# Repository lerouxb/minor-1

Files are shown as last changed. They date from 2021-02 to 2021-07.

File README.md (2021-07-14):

# minor-1

Credit card sized capacitive touch toy piano.

Just the absolute minimum:

* QT60140 16 key touch sensor
* ATtiny1614 microcontroller
* Piezo transducer
* MCP6001R op-amp as buffer for the piezo
* CR2032 coin cell battery
* SPDT power switch
* 13 keys, octave +/- and change sound touch buttons
* Currently unpopulated footprint for NOR flash
* P-channel MOSFET for completely cutting power

This uses the attiny's 8-bit DAC at 25khz to play notes. The microcontroller can shut down power to the op-amp/piezo and the flash chip when not in use. It also sleeps until a touch button is pressed or until there's activity on the serial port.

There's a simple browser page to log the button presses, read status and read/write the setups. Useful for configurating the touch controller. Could be useful in future for programming the NOR flash or configuring the sounds.

Still very much a work in progress, but it can already play tunes.

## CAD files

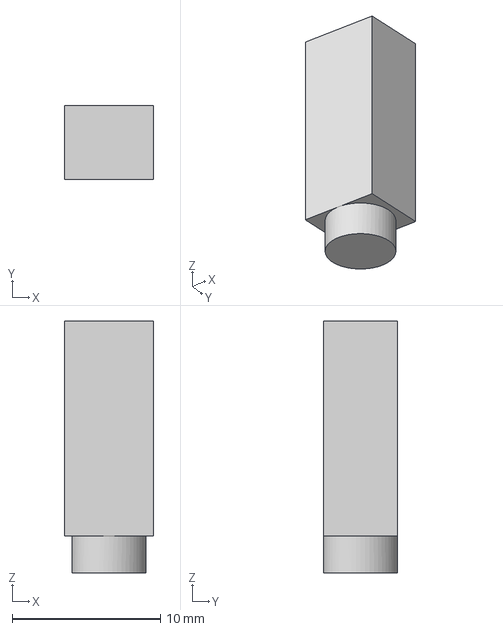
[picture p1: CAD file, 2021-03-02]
pcb/minor-1/footprints/SJ-3523-SMT-TR.step
6.00 x 5.00 x 17.0 mm

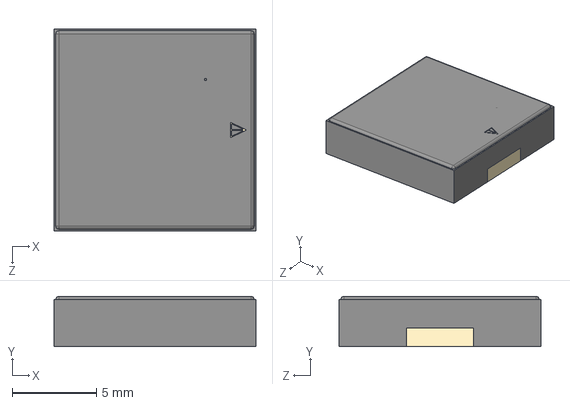
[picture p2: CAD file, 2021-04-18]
pcb/minor-cap/PKLCS1212E2000-R1--3DModel-STEP-56544.STEP
12.0 x 3.00 x 12.0 mm

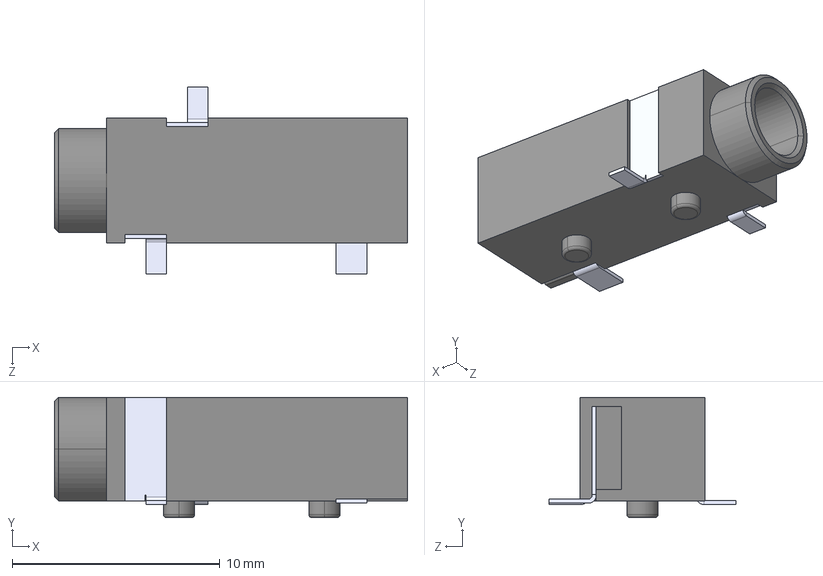
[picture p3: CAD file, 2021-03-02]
pcb/minor-1/footprints/SJ-3523-SMT-TR--3DModel-STEP-56544.STEP
17.0 x 5.80 x 9.00 mm

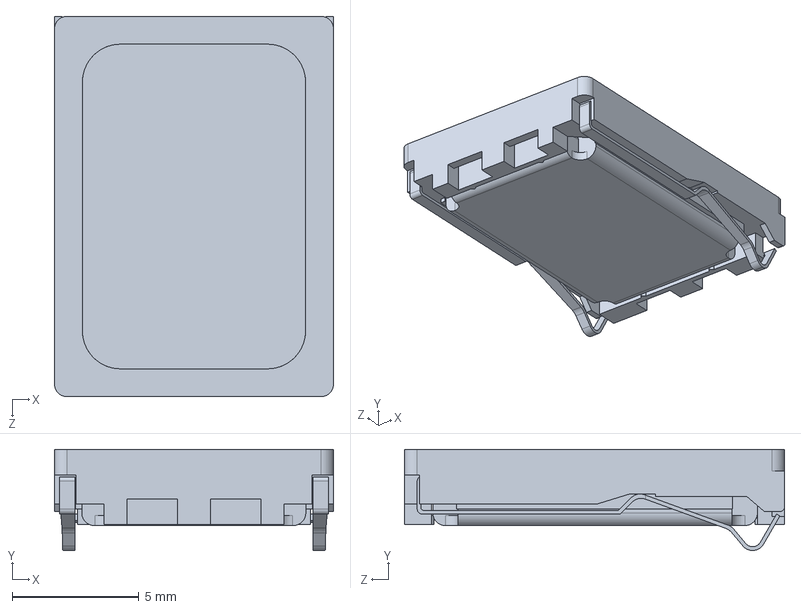
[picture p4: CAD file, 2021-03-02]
pcb/minor-1/footprints/CUI_DEVICES_CMS-15113-078S.step
11.0 x 3.98 x 15.0 mm

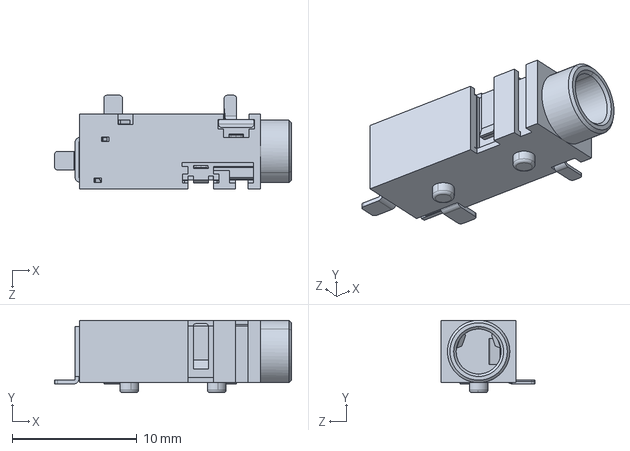
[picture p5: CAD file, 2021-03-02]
pcb/minor-1/footprints/CUI_DEVICES_SJ2-3592B-SMT-TR.step
19.0 x 5.80 x 7.50 mm

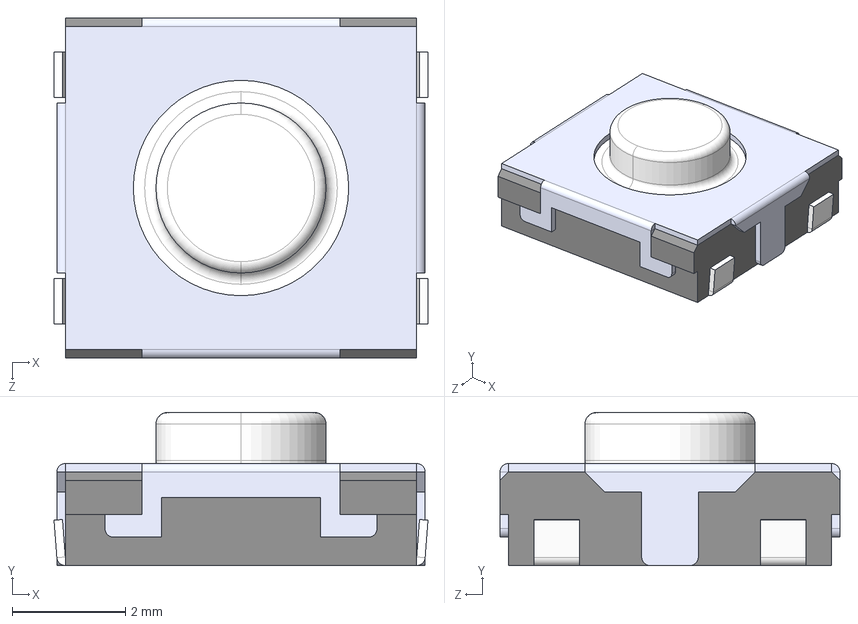
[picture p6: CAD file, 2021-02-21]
pcb/minor-1/footprints/EVQ-Q2B02W--3DModel-STEP-1.STEP
6.60 x 2.70 x 6.00 mm

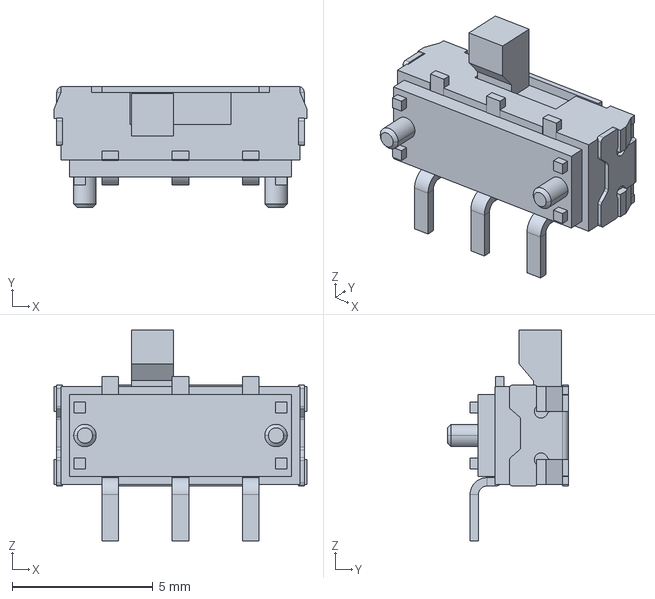
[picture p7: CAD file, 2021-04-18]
pcb/minor-cap/JS102011SAQN--3DModel-Eagle-1.STEP
9.00 x 4.30 x 7.50 mm

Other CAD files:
pcb/minor-1/footprints/SJ-3523-SMT-TR.f3d

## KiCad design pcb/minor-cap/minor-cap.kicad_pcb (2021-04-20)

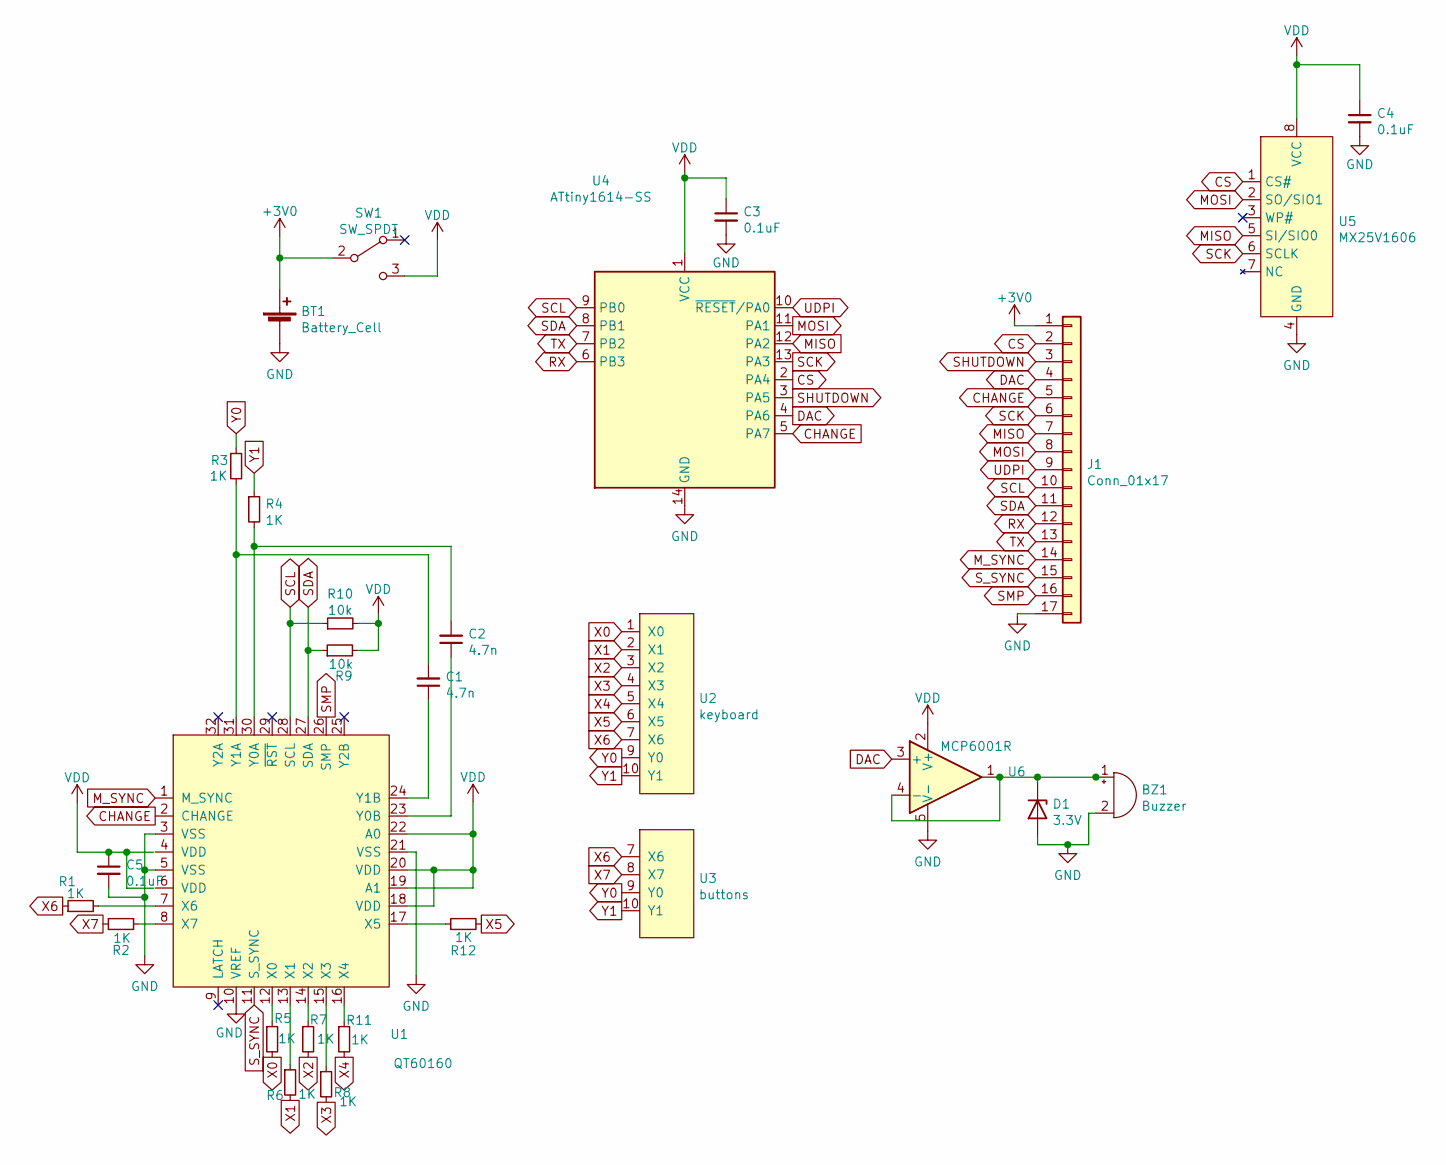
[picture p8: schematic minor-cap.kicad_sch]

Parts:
BT1: Battery_Cell; BatteryHolder_Keystone_3034_1x20mm
BZ1: Buzzer; Buzzer_Murata_PKLCS1212E
C1, C2: 4.7n; C_0603_1608Metric
C3, C4, C5: 0.1uF; C_0603_1608Metric
D1: 3.3V; D_SOD-323
J1: Conn_01x17; 01x17_custom
R1, R2, R3, R4, R5, R6, R7, R8, R11, R12: 1K; R_0603_1608Metric
R9, R10: 10k; R_0603_1608Metric
SW1: SW_SPDT; SW_SPDT_CK-JS102011SAQN
U1: QT60160; QFN-32-1EP_5x5mm_P0.5mm_EP3.1x3.1mm
U2: keyboard; 13-keys
U3: buttons; 3-buttons
U4: ATtiny1614-SS; SOIC-14_3.9x8.7mm_P1.27mm
U5: MX25V1606; SOP-8_3.9x4.9mm_P1.27mm
U6: MCP6001R; SOT-23-5

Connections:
+3V0: BT1.1 (+), J1.1, SW1.2 (B)
CHANGE: J1.5, U1.2 (CHANGE), U4.5 (PA7)
CS: J1.2, U4.2 (PA4), U5.1 (CS#)
DAC: J1.4, U4.4 (PA6), U6.3 (+)
GND: BT1.2 (-), BZ1.2 (+), C3.2, C4.2, C5.2, D1.2 (A), J1.17, U1.3 (VSS), U1.5 (VSS), U1.10 (VREF), U1.21 (VSS), U4.14 (GND), U5.4 (GND), U6.5 (V-)
MISO: J1.7, U4.12 (PA2), U5.5 (SI/SIO0)
MOSI: J1.8, U4.11 (PA1), U5.2 (SO/SIO1)
M_SYNC: J1.14, U1.1 (M_SYNC)
unnamed: BZ1.1 (-), D1.1 (K), U6.1, U6.4 (-)
unnamed: C1.1, U1.24 (Y1B)
unnamed: C1.2, R3.2, U1.31 (Y1A)
unnamed: C2.1, U1.23 (Y0B)
unnamed: C2.2, R4.2, U1.30 (Y0A)
unnamed: R1.2, U1.7 (X6)
unnamed: R2.1, U1.8 (X7)
unnamed: R5.1, U1.12 (X0)
unnamed: R6.1, U1.13 (X1)
unnamed: R7.1, U1.14 (X2)
unnamed: R8.1, U1.15 (X3)
unnamed: R11.1, U1.16 (X4)
unnamed: R12.1, U1.17 (X5)
RX: J1.12, U4.6 (PB3)
SCK: J1.6, U4.13 (PA3), U5.6 (SCLK)
SCL: J1.10, R10.1, U1.28 (SCL), U4.9 (PB0)
SDA: J1.11, R9.1, U1.27 (SDA), U4.8 (PB1)
SHUTDOWN: J1.3, U4.3 (PA5)
SMP: J1.16, U1.26 (SMP)
S_SYNC: J1.15, U1.11 (S_SYNC)
TX: J1.13, U4.7 (PB2)
UDPI: J1.9, U4.10 (~RESET~/PA0)
VDD: C3.1, C4.1, C5.1, R9.2, R10.2, SW1.3 (C), U1.18 (VDD), U1.19 (A1), U1.20 (VDD), U1.22 (A0), U4.1 (VCC), U5.8 (VCC), U6.2 (V+)
X0: R5.2, U2.1 (X0)
X1: R6.2, U2.2 (X1)
X2: R7.2, U2.3 (X2)
X3: R8.2, U2.4 (X3)
X4: R11.2, U2.5 (X4)
X5: R12.2, U2.6 (X5)
X6: R1.1, U2.7 (X6), U3.7 (X6)
X7: R2.2, U3.8 (X7)
Y0: R3.1, U2.9 (Y0), U3.9 (Y0)
Y1: R4.1, U2.10 (Y1), U3.10 (Y1)

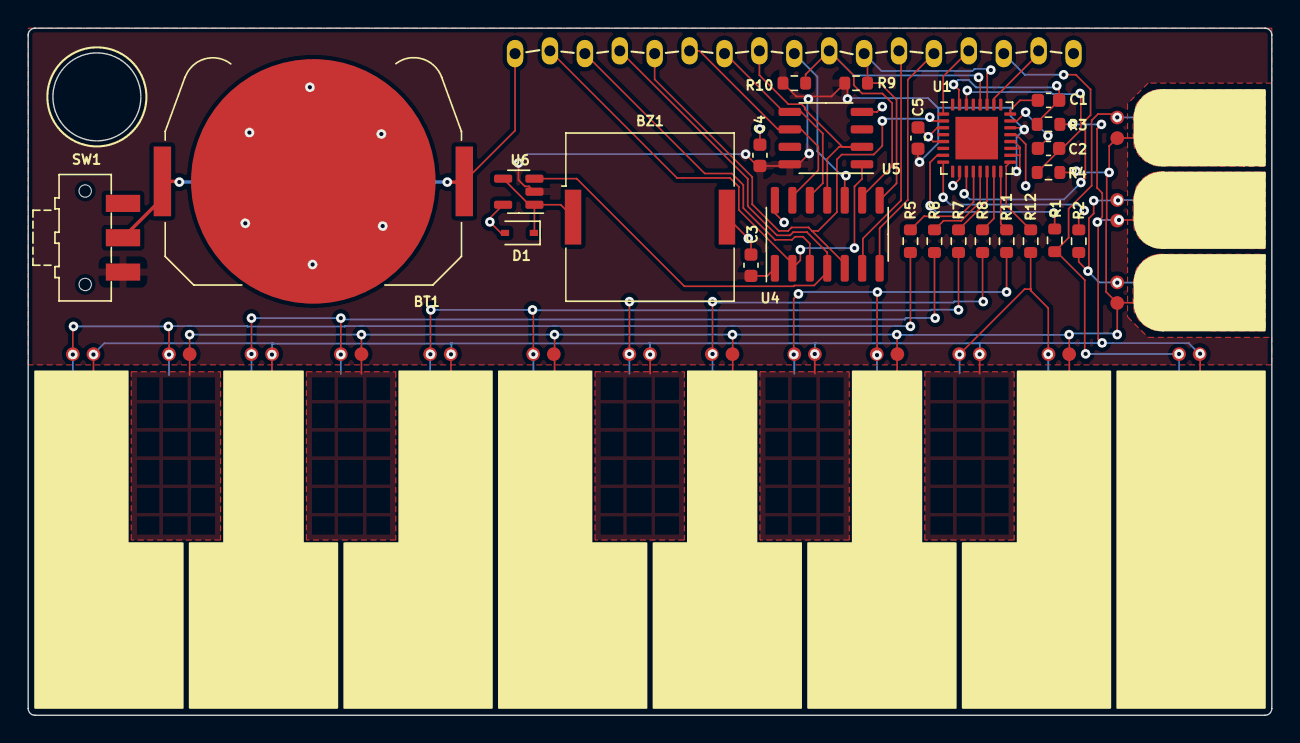
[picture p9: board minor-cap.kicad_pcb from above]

Board: 2 copper layers, 90.5 x 50.0 mm, 28 parts (0 on the bottom side), 41 nets.

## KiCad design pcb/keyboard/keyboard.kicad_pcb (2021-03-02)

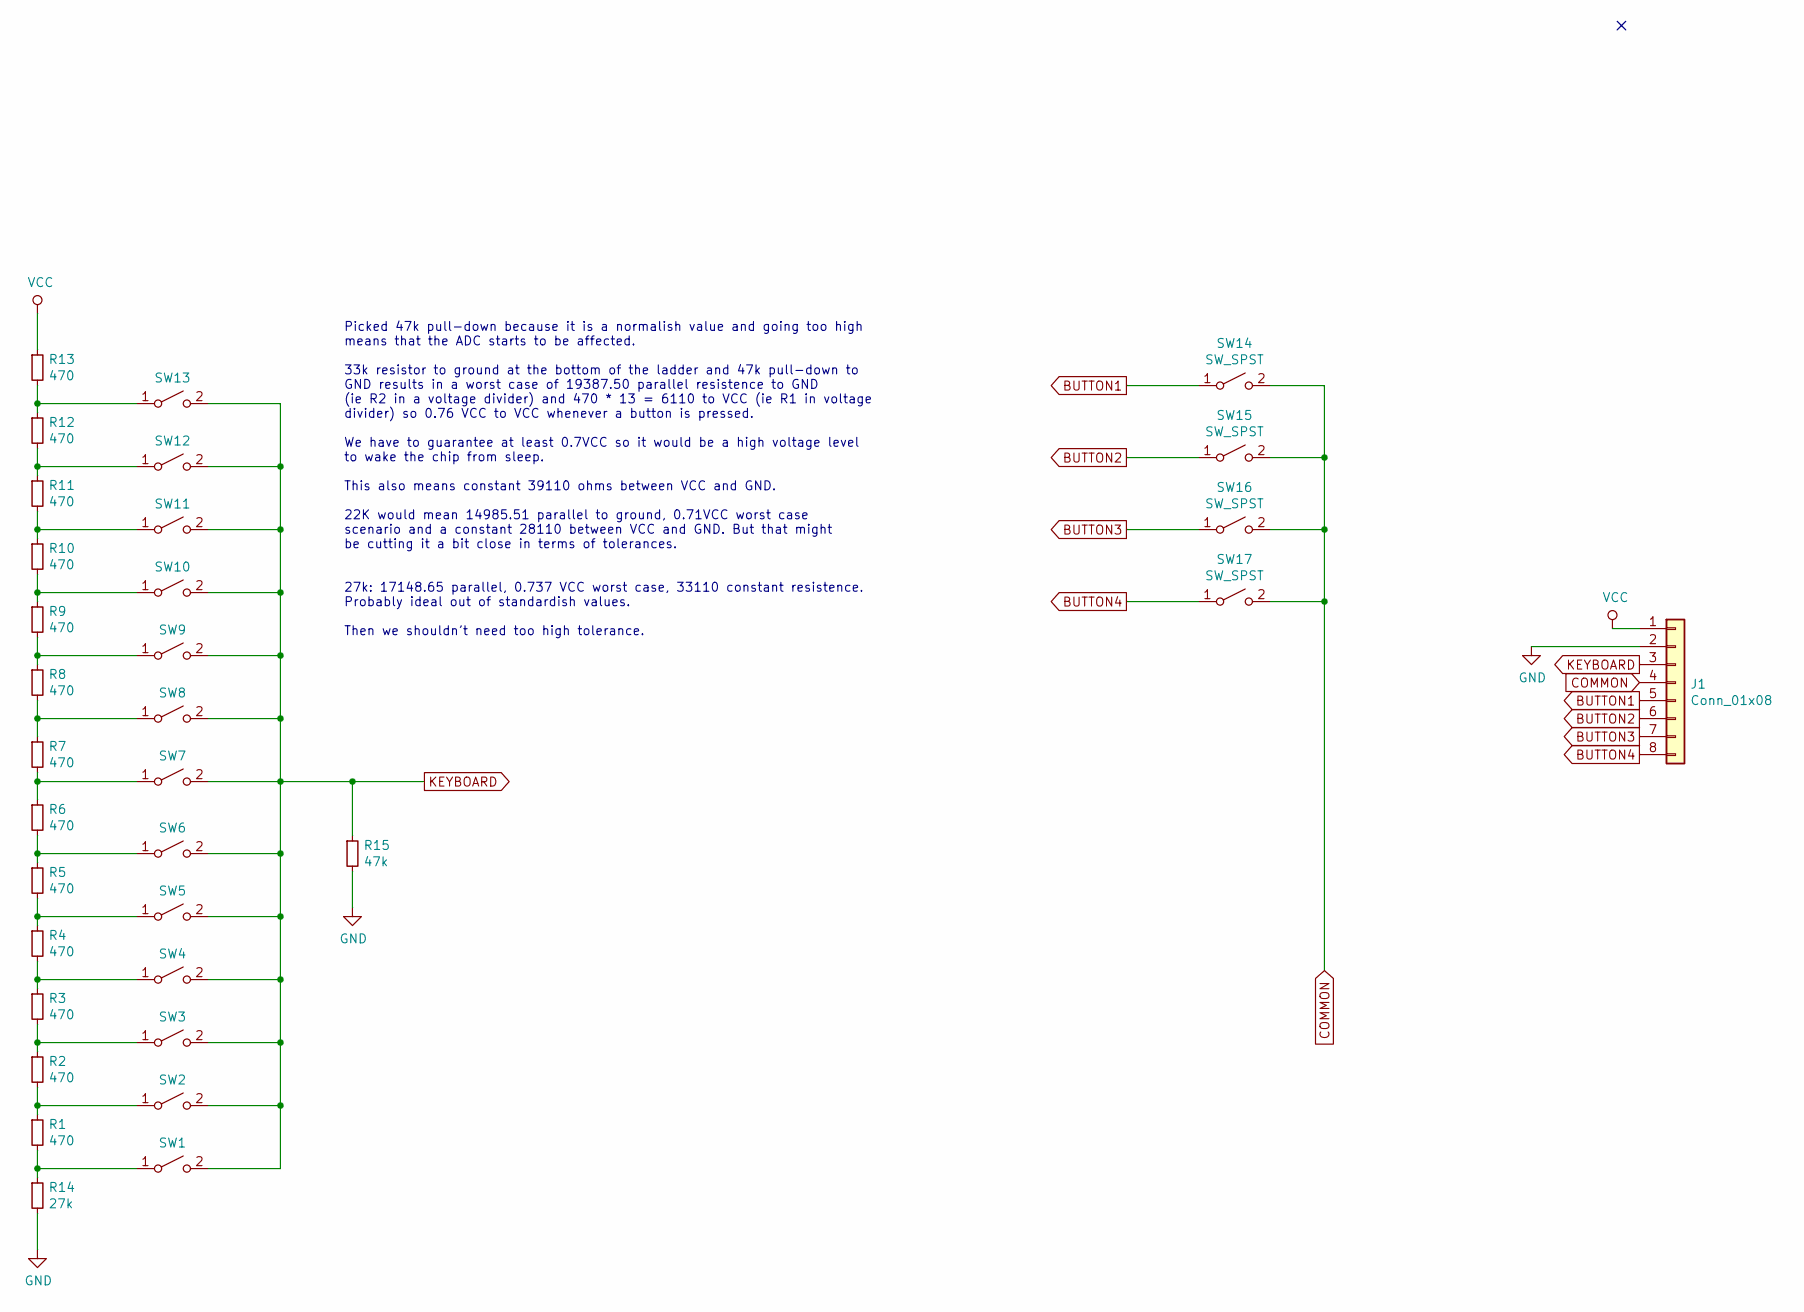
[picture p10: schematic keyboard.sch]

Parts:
J1: Conn_01x08; Pin_Header_Straight_1x08_Pitch2.54mm
R1, R2, R3, R4, R5, R6, R7, R8, R9, R10, R11, R12, R13: 470; R_0603
R14: 27k; R_0603
R15: 47k; R_0603
SW1, SW2, SW3, SW4, SW5, SW6, SW7, SW8, SW9, SW10, SW11, SW12, SW13, SW14, SW15, SW16, SW17: SW_SPST; EVQ-Q2B03W

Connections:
BUTTON1: J1.5, SW14.1 (A)
BUTTON2: J1.6, SW15.1 (A)
BUTTON3: J1.7, SW16.1 (A)
BUTTON4: J1.8, SW17.1 (A)
COMMON: J1.4, SW14.2 (B), SW15.2 (B), SW16.2 (B), SW17.2 (B)
GND: J1.2, R14.2, R15.2
KEYBOARD: J1.3, R15.1, SW1.2 (B), SW2.2 (B), SW3.2 (B), SW4.2 (B), SW5.2 (B), SW6.2 (B), SW7.2 (B), SW8.2 (B), SW9.2 (B), SW10.2 (B), SW11.2 (B), SW12.2 (B), SW13.2 (B)
unnamed: R1.1, R2.2, SW2.1 (A)
unnamed: R1.2, R14.1, SW1.1 (A)
unnamed: R2.1, R3.2, SW3.1 (A)
unnamed: R3.1, R4.2, SW4.1 (A)
unnamed: R4.1, R5.2, SW5.1 (A)
unnamed: R5.1, R6.2, SW6.1 (A)
unnamed: R6.1, R7.2, SW7.1 (A)
unnamed: R7.1, R8.2, SW8.1 (A)
unnamed: R8.1, R9.2, SW9.1 (A)
unnamed: R10.1, R11.2, SW11.1 (A)
unnamed: R9.1, R10.2, SW10.1 (A)
unnamed: R11.1, R12.2, SW12.1 (A)
unnamed: R12.1, R13.2, SW13.1 (A)
VCC: J1.1, R13.1

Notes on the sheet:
Picked 47k pull-down because it is a normalish value and going too high means that the ADC starts to be affected. 33k resistor to ground at the bottom of the ladder and 47k pull-down to GND results in a worst case of 19387.50 parallel resistence to GND (ie R2 in a voltage divider) and 470 * 13 = 61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

Board: 2 copper layers, 33 parts (0 on the bottom side), 21 nets, no tracks yet.

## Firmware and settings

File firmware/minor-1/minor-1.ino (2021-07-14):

#include <avr/sleep.h>
#include "pins.h"
#include "engine.h"
#include "interface.h"

// TODO: check every menu option

#ifndef MILLIS_USE_TIMERD0
#error "This sketch is written for use with TCD0 as the millis timing source"
#endif

// engine.cpp
extern boolean isPlaying; // TODO: make it a function?

// globals used by interface and engine
volatile uint32_t tick = 0;
volatile uint8_t sample = 127;

// globals used by interface
volatile bool touchChanged = false;
volatile bool goToSleep = false;


void setup() {

    DACReference(INTERNAL2V5);

    // setup a timer overflow interrupt to fire at 25khz
    // system clock is 20Mhz. Prescaler is 16. Period is 49 (so it will be 49+1 = 50)
    TCA0.SINGLE.INTCTRL = 0 << TCA_SINGLE_CMP0_bp   /* Compare 0 Interrupt: disabled */
                          | 0 << TCA_SINGLE_CMP1_bp /* Compare 1 Interrupt: disabled */
                          | 0 << TCA_SINGLE_CMP2_bp /* Compare 2 Interrupt: disabled */
                          | 1 << TCA_SINGLE_OVF_bp; /* Overflow Interrupt: enabled */

    TCA0.SINGLE.PER = 49; /* 49 + 1 == 50 */

    TCA0.SINGLE.CTRLA = TCA_SINGLE_CLKSEL_DIV16_gc /* System Clock / 16 */
                        | 1 << TCA_SINGLE_ENABLE_bp /* Module Enable: enabled */;

    //pinMode(LED_PIN, OUTPUT);
    pinMode(DAC_PIN, OUTPUT);
    pinMode(SHUTDOWN_PIN, OUTPUT);
    pinMode(CHANGE_PIN, INPUT_PULLUP);

    // PIN_PA7
    PORTA.PIN7CTRL |= 0x01; // interrupt on change

    // TODO: make sure all pins are dealt with from a power consumption perspective

    Serial.begin(57600); // at 115200 it wakes too slowly from sleep to be able to read serial communications
    Wire.begin();

    setupInterface();

    Serial.println("OK");

    recalibrateTouch();

    Serial.println("recalibrated");

    // TODO: uart doesn't stay active during power down. it can stay active during standby if we enable that (somewhere?), but maybe we can just set a pin interrupt on RX?
    set_sleep_mode(SLEEP_MODE_STANDBY);
    USART0.CTRLB |= USART_SFDEN_bm; // enable start of frame detection mode
    sleep_enable();
}


void loop() {

    updateInterface();

    // clear interrupts before double-checking to eliminate race conditions
    // see https://www.nongnu.org/avr-libc/user-manual/group__avr__sleep.html
    cli();
    if (goToSleep) {
        // reset goToSleep regardless so that it will be re-set if we don't go to sleep and it still applies
        goToSleep = false;

        // don't go to sleep if there are unprocessed touch events because the touch sensor won't set the change pin high again until we read it. Therefore we have to make very sure we read everything and that it is low so that things don't get stuck
        if (!touchChanged && !isPlaying && digitalRead(CHANGE_PIN) == LOW) {
            sei();
            Serial.flush();
            Serial.println("going to sleep");
            Serial.flush();

            // tripple-check because interrupts are on and we printed things which takes time
            cli();
            if (digitalRead(CHANGE_PIN) == LOW) {
                sei(); // in theory sleep_cpu() straight after sei() is atomic
                sleep_cpu();
            }

            Serial.println("awake!");
        }
    }

    sei(); // in case either if up top was false
}

ISR(TCA0_OVF_vect) {

    //digitalWriteFast(LED_PIN, true);

    ++tick;

    if (isPlaying) {
        digitalWriteFast(SHUTDOWN_PIN, false); // on before next sample
    }
    else {
        goToSleep = true; // this is so the main loop can put the chip to sleep after this interrupt ran
        digitalWriteFast(SHUTDOWN_PIN, true); // off before next sample
    }

    // write the previously calculated sample first so the timing is reliable no matter how long it takes to calculate the next sample
    analogWrite(DAC_PIN, sample);

    // calculate the sample for next time
    sample = nextSample();

    //digitalWriteFast(LED_PIN, false); // TODO: optimise

    // The interrupt flag has to be cleared manually
    TCA0.SINGLE.INTFLAGS = TCA_SINGLE_OVF_bm;
}

ISR(PORTA_PORT_vect) {
    byte flags = PORTA.INTFLAGS;
    PORTA.INTFLAGS = flags; //clear flags

    if (digitalRead(CHANGE_PIN) == HIGH) {
        touchChanged = true;
    }
}

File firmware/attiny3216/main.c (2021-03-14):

#include <string.h>
#include <atmel_start.h>
#include <util/delay.h>
#include "notes.h"
#include "waveforms.h"

// about 25000 ticks per second
#define DEBOUNCE_TICKS 1250
#define REPEAT_TICKS1 6000 // first repeat is slower to prevent accidents
#define REPEAT_TICKS2 2000

volatile adc_result_t ADC_0_measurement;
extern volatile uint32_t tick;

// sound stuff
int32_t jump = 44946936; // Middle C
uint8_t octave = 0;
waveform_t waveform = Pulse;

// button stuff
uint32_t last_tick = 0;
uint16_t bounce = 0;
uint16_t repeat = 0;
bool repeating = false;

void my_function ();


int8_t check_up_down() {

    int8_t delta = 0;

    // tick wraps about once every 2 days :)
    if (last_tick > tick) {
        last_tick = 0;
    }

    while (last_tick < tick) {
        ++last_tick;

        if (bounce > 0) {
            if (BTN1_get_level() == true && BTN2_get_level() == true) {
                --bounce;
                if (bounce == 0) {
                    repeating = false;
                }
            }
            else {
                bounce = DEBOUNCE_TICKS; // reset to the start so that bouncing switches don't whittle away at the count
            }
        }

        if (repeat > 0) {
            --repeat;
        }
    }

    if (bounce == 0 || repeat == 0) {
        if (BTN1_get_level() == false) {
            delta = -1;
        }
        else if (BTN2_get_level() == false) {
            delta = 1;
        }

        if (delta != 0) {
            bounce = DEBOUNCE_TICKS;
            if (repeating) {
                repeat = REPEAT_TICKS2;
            }
            else {
                repeating = true;
                repeat = REPEAT_TICKS1;
            }
        }
    }

    return delta;
}

int8_t get_key(adc_result_t value) {

    // TODO: subtract 10, use as start, check > that and < that plus 20. Should be faster.
    unsigned int midpoint = 755;
    int8_t key = -1;

    for (int8_t i=0; i<13; ++i) {
        if (value > (midpoint - 10) && value < (midpoint + 10)) {
            key = i;
            break;
        }
        midpoint += 20;
    }

    return key;
}

int main(void) {

    atmel_start_init();

    DISABLE_set_level(false); // start off
    DAC_0_enable();

    sei();


    while (1) {
        //LED_toggle_level(); // produces tons of noise that affects the DAC

        int8_t delta = check_up_down();

        if (delta != 0) {
            if (octave + delta >= 0 && octave + delta <= 7) {
                octave += delta;
                printf("%d\r\n", octave);
                my_function();
            }
        }

        ADC_0_measurement = ADC_0_get_conversion(4);

        int8_t key = get_key(ADC_0_measurement);

        if (key == -1) {
            // Prefer to keep the previous note if it looks like something was pressed because the most likely explanation is that two keys are held down and it is _just_ barely putting us out of range of either of them.
            if (ADC_0_measurement < 745) {
                jump = -1;
            }
        }
        else {
            //jump = notes[39 - 24 + key];
            jump = notes[3 + octave * 12 + key];
        }
    }
}

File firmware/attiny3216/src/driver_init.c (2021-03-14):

/**
 * \file
 *
 * \brief Driver initialization.
 *
 (c) 2020 Microchip Technology Inc. and its subsidiaries.

    Subject to your compliance with these terms,you may use this software and
    any derivatives exclusively with Microchip products.It is your responsibility
    to comply with third party license terms applicable to your use of third party
    software (including open source software) that may accompany Microchip software.

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
    IN NO EVENT WILL MICROCHIP BE LIABLE FOR ANY INDIRECT, SPECIAL, PUNITIVE,
    INCIDENTAL OR CONSEQUENTIAL LOSS, DAMAGE, COST OR EXPENSE OF ANY KIND
    WHATSOEVER RELATED TO THE SOFTWARE, HOWEVER CAUSED, EVEN IF MICROCHIP HAS
    BEEN ADVISED OF THE POSSIBILITY OR THE DAMAGES ARE FORESEEABLE. TO THE
    FULLEST EXTENT ALLOWED BY LAW, MICROCHIP'S TOTAL LIABILITY ON ALL CLAIMS IN
    ANY WAY RELATED TO THIS SOFTWARE WILL NOT EXCEED THE AMOUNT OF FEES, IF ANY,
    THAT YOU HAVE PAID DIRECTLY TO MICROCHIP FOR THIS SOFTWARE.
 *
 */

/*
 * Code generated by START.
 *
 * This file will be overwritten when reconfiguring your START project.
 * Please copy examples or other code you want to keep to a separate file
 * to avoid losing it when reconfiguring.
 */

#include "driver_init.h"
#include <system.h>

/* Configure pins and initialize registers */
void ADC_0_initialization(void)
{

	// Disable digital input buffer
	KEYS_set_isc(PORT_ISC_INPUT_DISABLE_gc);
	// Disable pull-up resistor
	KEYS_set_pull_mode(PORT_PULL_OFF);

	ADC_0_init();
}

/* configure the pins and initialize the registers */
void USART_0_initialization(void)
{

	// Set pin direction to input
	RX_set_dir(PORT_DIR_IN);

	RX_set_pull_mode(
	    // <y> Pull configuration
	    // <id> pad_pull_config
	    // <PORT_PULL_OFF"> Off
	    // <PORT_PULL_UP"> Pull-up
	    PORT_PULL_OFF);

	// Set pin direction to output

	TX_set_level(
	    // <y> Initial level
	    // <id> pad_initial_level
	    // <false"> Low
	    // <true"> High
	    false);

	TX_set_dir(PORT_DIR_OUT);

	USART_0_init();
}

void TIMER_0_initialization(void)
{

	TIMER_0_init();
}

/* configure pins and initialize registers */
void DAC_0_initialization(void)
{

	// Disable digital input buffer
	DAC_set_isc(PORT_ISC_INPUT_DISABLE_gc);
	// Disable pull-up resistor
	DAC_set_pull_mode(PORT_PULL_OFF);

	DAC_0_init();
}

/* configure pins and initialize registers */
void I2C_0_initialization(void)
{

	SCL_set_level(
	    // <y> Initial level
	    // <id> pad_initial_level
	    // <false"> Low
	    // <true"> High
	    false);

	SCL_set_dir(
	    // <y> Pin direction
	    // <id> pad_dir
	    // <PORT_DIR_OFF"> Off
	    // <PORT_DIR_IN"> In
	    // <PORT_DIR_OUT"> Out
	    PORT_DIR_OUT);

	SCL_set_pull_mode(
	    // <y> Pull configuration
	    // <id> pad_pull_config
	    // <PORT_PULL_OFF"> Off
	    // <PORT_PULL_UP"> Pull-up
	    PORT_PULL_OFF);

	SCL_set_inverted(
	    // <y> Invert I/O on pin
	    // <id> pad_invert
	    // <false"> Not inverted
	    // <true"> Inverted
	    false);

	SCL_set_isc(
	    // <y> Pin Input/Sense Configuration
	    // <id> pad_isc
	    // <PORT_ISC_INTDISABLE_gc"> Interrupt disabled but input buffer enabled
	    // <PORT_ISC_BOTHEDGES_gc"> Sense Both Edges
	    // <PORT_ISC_RISING_gc"> Sense Rising Edge
	    // <PORT_ISC_FALLING_gc"> Sense Falling Edge
	    // <PORT_ISC_INPUT_DISABLE_gc"> Digital Input Buffer disabled
	    // <PORT_ISC_LEVEL_gc"> Sense low Level
	    PORT_ISC_INTDISABLE_gc);

	/* set the alternate pin mux */
	PORTMUX.CTRLB |= PORTMUX_TWI0_bm;

	SDA_set_level(
	    // <y> Initial level
	    // <id> pad_initial_level
	    // <false"> Low
	    // <true"> High
	    false);

	SDA_set_dir(
	    // <y> Pin direction
	    // <id> pad_dir
	    // <PORT_DIR_OFF"> Off
	    // <PORT_DIR_IN"> In
	    // <PORT_DIR_OUT"> Out
	    PORT_DIR_OUT);

	SDA_set_pull_mode(
	    // <y> Pull configuration
	    // <id> pad_pull_config
	    // <PORT_PULL_OFF"> Off
	    // <PORT_PULL_UP"> Pull-up
	    PORT_PULL_OFF);

	SDA_set_inverted(
	    // <y> Invert I/O on pin
	    // <id> pad_invert
	    // <false"> Not inverted
	    // <true"> Inverted
	    false);

	SDA_set_isc(
	    // <y> Pin Input/Sense Configuration
	    // <id> pad_isc
	    // <PORT_ISC_INTDISABLE_gc"> Interrupt disabled but input buffer enabled
	    // <PORT_ISC_BOTHEDGES_gc"> Sense Both Edges
	    // <PORT_ISC_RISING_gc"> Sense Rising Edge
	    // <PORT_ISC_FALLING_gc"> Sense Falling Edge
	    // <PORT_ISC_INPUT_DISABLE_gc"> Digital Input Buffer disabled
	    // <PORT_ISC_LEVEL_gc"> Sense low Level
	    PORT_ISC_INTDISABLE_gc);

	/* set the alternate pin mux */
	PORTMUX.CTRLB |= PORTMUX_TWI0_bm;

	I2C_0_init();
}

/**
 * \brief System initialization
 */
void system_init()
{
	mcu_init();

	/* PORT setting on PA5 */

	// Set pin direction to output

	DISABLE_set_level(
	    // <y> Initial level
	    // <id> pad_initial_level
	    // <false"> Low
	    // <true"> High
	    true);

	DISABLE_set_dir(PORT_DIR_OUT);

	/* PORT setting on PB0 */

	// Set pin direction to output

	LED_set_level(
	    // <y> Initial level
	    // <id> pad_initial_level
	    // <false"> Low
	    // <true"> High
	    false);

	LED_set_dir(PORT_DIR_OUT);

	/* PORT setting on PC0 */

	// Set pin direction to input
	BTN1_set_dir(PORT_DIR_IN);

	BTN1_set_pull_mode(
	    // <y> Pull configuration
	    // <id> pad_pull_config
	    // <PORT_PULL_OFF"> Off
	    // <PORT_PULL_UP"> Pull-up
	    PORT_PULL_UP);

	/* PORT setting on PC1 */

	// Set pin direction to input
	BTN2_set_dir(PORT_DIR_IN);

	BTN2_set_pull_mode(
	    // <y> Pull configuration
	    // <id> pad_pull_config
	    // <PORT_PULL_OFF"> Off
	    // <PORT_PULL_UP"> Pull-up
	    PORT_PULL_UP);

	/* PORT setting on PC2 */

	// Set pin direction to input
	BTN3_set_dir(PORT_DIR_IN);

	BTN3_set_pull_mode(
	    // <y> Pull configuration
	    // <id> pad_pull_config
	    // <PORT_PULL_OFF"> Off
	    // <PORT_PULL_UP"> Pull-up
	    PORT_PULL_UP);

	CLKCTRL_init();

	VREF_0_init();

	ADC_0_initialization();

	USART_0_initialization();

	TIMER_0_initialization();

	DAC_0_initialization();

	CPUINT_init();

	SLPCTRL_init();

	I2C_0_initialization();

	BOD_init();
}

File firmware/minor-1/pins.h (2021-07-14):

#ifndef PINS_H
#define PINS_H

#include <arduino.h>

//#define LED_PIN (PIN_PB4)
#define SHUTDOWN_PIN (PIN_PA5)
#define DAC_PIN (PIN_PA6)
#define CHANGE_PIN (PIN_PA7)

#endif

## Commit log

2021-02-21 add TIMER_0
2021-02-27 ignore some stuff
    [keyboard.sch]
2021-02-28 0.55V DAC Ref
2021-03-02 pcb mockup
    [CUI_DEVICES_CMS-15113-078S.step, CUI_DEVICES_SJ2-3592B-SMT-TR.step, EVQ-Q2B02W--3DModel-STEP-1.STEP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]
2021-03-02 LED, button debounce
2021-03-02 remove unused file
    [minor.cfg]
2021-03-03 octave switching
2021-03-14 back to arduino
2021-04-18 before silkscreen
    [JS102011SAQN--3DModel-Eagle-1.STEP, PKLCS1212E2000-R1--3DModel-STEP-56544.STEP, minor-1.kicad_pcb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]
